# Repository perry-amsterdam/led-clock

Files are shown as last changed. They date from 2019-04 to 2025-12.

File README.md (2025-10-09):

# LED Clock with ESP32, FreeRTOS & WS2812B




A **DIY LED clock** built with WS2812B LEDs, an IKEA photo frame, laser-cut parts, and an **ESP32** running **FreeRTOS**.  
The hardware (clock face, laser-cut design) is ready ✅. The software runs on a modern ESP32 + FreeRTOS platform and is fully configurable through a captive Wi-Fi portal.

---

## ✨ Features

* Automatic time synchronization via **NTP**
* **Timezone detection** via IP geolocation
* **mDNS** discovery on the local network
* **WPS** connection option (Wi-Fi Protected Setup)

* Wi-Fi setup: if no connection is found, the clock starts an **Access Point + captive portal**
* Written in **C/C++ with FreeRTOS**
* Expandable platform: animations, integrations, and artistic variations
* Future **API server** + **Flutter app** for remote control

### FreeRTOS Tasks
- `task_wifi` – connect and reconnect to the network  
- `task_time` – synchronize and monitor time  
- `task_render` – draw the clock on the LED strip  
- `task_portal` – run the captive portal when offline  
- `task_led` – update the status LED  

---

## 🖥️ Software Setup

1. Install the required tools:
   * [Arduino CLI](https://arduino.github.io/arduino-cli/latest/) or [Arduino IDE](https://www.arduino.cc/en/software)  
   * ESP32 board support (via Board Manager)
   * `make` (for the workflow with the Makefile)
   * [Flutter](https://flutter.dev/) (optional, for the mobile app)

2. Use the **Makefile** for a quick workflow:

   ```bash
   make deps       # install esp32 core + libraries (Adafruit NeoPixel)
   make build      # compile
   make upload     # flash (PORT=/dev/ttyUSB0)
   make monitor    # serial monitor (115200 baud)
   ```

   Variables:
   - `PORT` – default `/dev/ttyACM0`
   - `BOARD` – default `esp32:esp32:esp32s3`
   - `FLASH_OPTS` – flash/PSRAM/partition settings

   Example:
   ```bash
   make PORT=/dev/ttyUSB0 MONITOR_BAUD=115200 monitor
   ```

3. First boot → configure Wi-Fi through the captive portal (`ESP32-Setup` / `configwifi`).

---

## ⚙️ Hardware Setup

* **Clock face** (laser-cut ✅, designed in LibreCAD):  
  Clock Face

* **WS2812B connectors**:
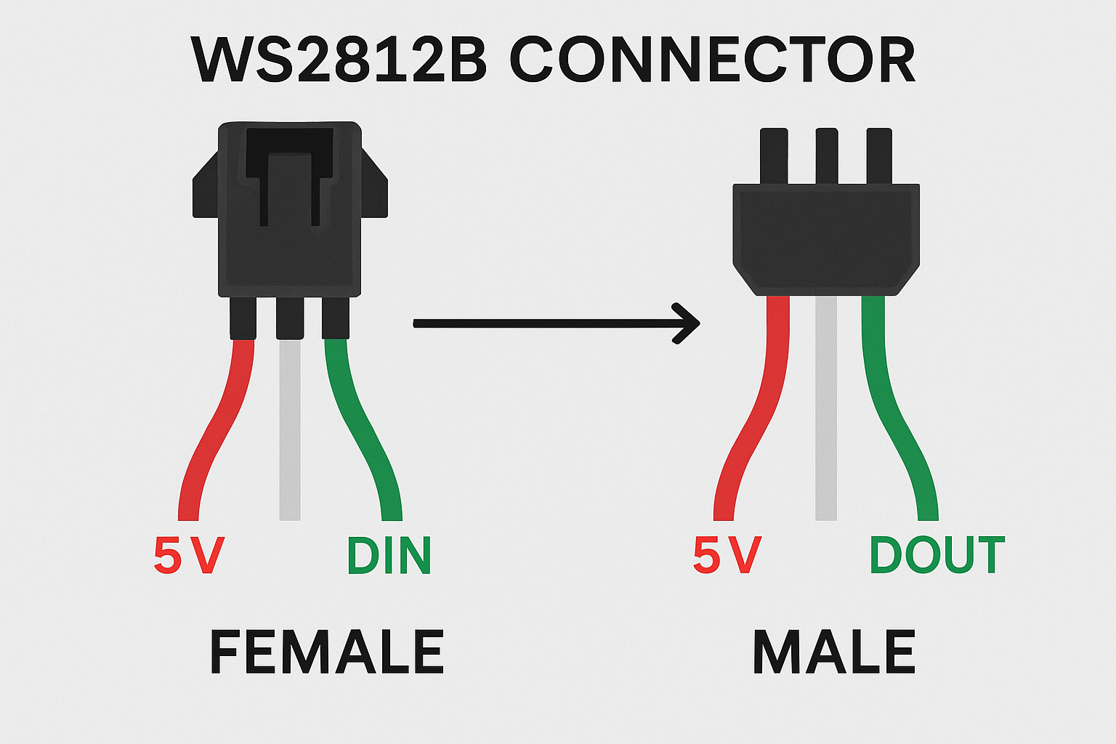
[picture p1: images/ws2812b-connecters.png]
Connector image
  

* **Parts list**:
  * IKEA frame 23x23 cm  
  * WS2812B LED strip or ring (5V)  
  * ESP32 devkit (WROOM/WROVER/S3)  
  * Cardboard/laser-cut front plate  

### Connections

- **GPIO 8** → DIN of the **clock LED strip (60 LEDs for minutes and seconds)**
- **GPIO 9** → DIN of the **clock LED strip (24 LEDs for 24 hours)**  
- **GPIO 48** → DIN of the **status LED**  
- **5V & GND** shared between ESP32 and all LEDs

### 📷 Wiring Diagram

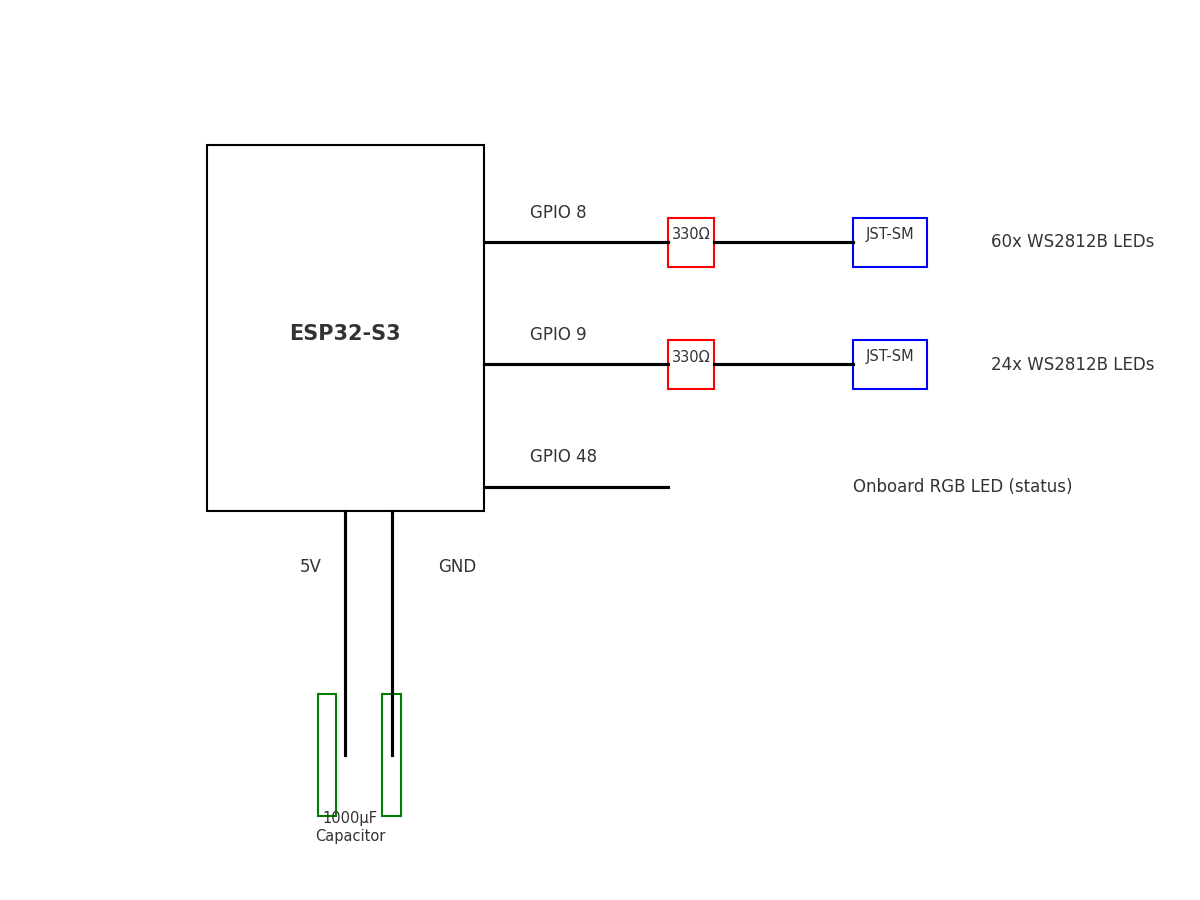
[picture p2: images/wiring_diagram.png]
Wiring Diagram


> ℹ️ The status LED (GPIO 48) is already present on the ESP32-S3 DevKit (built-in RGB LED).

### 📋 Pinout Table

| GPIO | Function | Description |
|---|---|---|
| 8 | Clock LEDs DIN  | Data input of WS2812B strip/matrix |
| 9 | Clock LEDs DIN  | Data input of WS2812B strip/matrix |
| 48 | Status LED (onboard) | Built-in RGB LED on ESP32 DevKit |
| 5V | LED Power | Ensure sufficient current capacity |
| GND  | Ground | Must be shared with LED power supply |

### 🔌 Power Consumption (approximate)

| LED Count | 100% brightness (mA) | 100% (A) | ~30% brightness (mA) | ~30% (A) |
|---:|---:|---:|---:|---:|
| 1 | 60 | 0.06 | 18 | 0.018 |
| 8 | 480 | 0.48 | 144 | 0.144 |
| 30 | 1800 | 1.80 | 540 | 0.54 |
| 60 | 3600 | 3.60 | 1080 | 1.08 |
| 100 | 6000 | 6.00 | 1800 | 1.80 |

**Tips**  
- Choose a power supply with **20–30% margin**  
- Use a **level shifter** for long LED strips  
- **GND** from the power supply must be connected to the ESP32  
- Lower `LED_BRIGHTNESS` to reduce power and heat

### NeoPixel Guidelines
1. **Capacitor** – 1000µF, 6.3V+ between V+ and GND  
2. **Resistor** – 300–500Ω in the data line  
3. **Level shifter** – recommended for 3.3V → 5V  

---

### 📡 Wi-Fi via WPS

Besides the captive portal, the clock also supports **WPS (Wi-Fi Protected Setup)** to connect to your network.  
This is useful if you don’t want to enter Wi-Fi credentials manually.

- **WPS PBC (Push Button Configuration)**: press the WPS button on your router and start the clock in WPS mode.  
- If the ESP32 successfully completes a WPS handshake, the credentials are stored in the chip’s NVS memory.  
- On the next boot, the clock automatically reconnects using these stored credentials.

⚠️ Note: not all ESP32 Arduino cores support WPS.  
Since **ESP32 Arduino core v3+**, `WiFi.beginWPSConfig()` has been removed. For those versions, use the captive portal instead.

---

## 🚀 Usage

1. Flash the firmware.  
2. On first boot, connect to **ESP32-Setup**.  
3. Open `http://192.168.4.1` and configure Wi-Fi.  
4. ESP32 connects → fetches time → displays clock on LED strips (GPIO 8 and 9).  
5. Status LED (GPIO 48) shows connection status.  

---

## 📸 Images

Frame
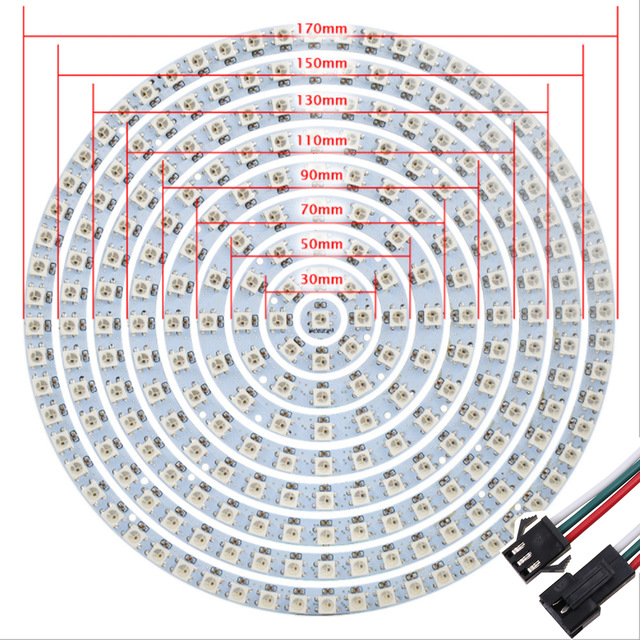
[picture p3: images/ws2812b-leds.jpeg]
WS2812B LEDs


---

## 🗺️ Roadmap

* [x] Laser-cut clock face  
* [x] Wi-Fi captive portal & NTP synchronization  
* [x] Automatic timezone detection via IP  
* [x] mDNS service  
* [ ] Wi-Fi WPS  
* [ ] API server on ESP32  
* [ ] Flutter app integration  
* [ ] Artistic clock variants  
* [ ] Animations & LED effects  
* [ ] Integration with Home Assistant / MQTT  
* [ ] Public release of PCB & 3D files  

---

## 🤝 Contributing

1. Fork the repo and create a feature branch:
   ```bash
   git checkout -b feature/new-feature
   ```
2. Commit your changes with clear messages  
3. Submit a Pull Request 🚀  

Tips: document hardware/software additions, add schematics or images, and keep commit messages short.

---

## 👤 Author

* **Perry Couprie** – initial development  
  GitHub: [perry-amsterdam](https://github.com/perry-amsterdam)

---

## 📐 CAD Tools

For designing parts such as the clock face and enclosure, you can use free open-source CAD tools:

### LibreCAD
* 2D CAD software, ideal for drawing the **laser-cut clock face**.
* Website: [https://librecad.org](https://librecad.org)

**Installation on Ubuntu:**
```bash
sudo apt update
sudo apt install librecad
```

### OpenSCAD
* 3D CAD software, perfect for designing **enclosures and 3D-printable parts**.
* Website: [https://openscad.org](https://openscad.org)

**Installation on Ubuntu:**
```bash
sudo apt update
sudo apt install openscad
```

Both programs are lightweight and available in the standard Ubuntu repositories.

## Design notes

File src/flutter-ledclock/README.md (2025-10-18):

# ledclock

A new Flutter project.

## Getting Started

This project is a starting point for a Flutter application.

A few resources to get you started if this is your first Flutter project:

- [Lab: Write your first Flutter app](https://docs.flutter.dev/get-started/codelab)
- [Cookbook: Useful Flutter samples](https://docs.flutter.dev/cookbook)

For help getting started with Flutter development, view the
[online documentation](https://docs.flutter.dev/), which offers tutorials,
samples, guidance on mobile development, and a full API reference.

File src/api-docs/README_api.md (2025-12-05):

# LED Clock REST API – Full Documentation

This directory contains the **OpenAPI specification** for the ESP32 LED Clock REST API.
The full specification is available in [`openapi.json`](./openapi.json) (version **1.5.0**).

---

## Overview

The LED Clock API provides system management and time-related endpoints for an ESP32-based LED clock running FreeRTOS. It enables you to:

* Check device health and uptime
* Reboot the system remotely
* Get or set the current timezone
* Retrieve a list of supported IANA timezones

All responses are in JSON format.

---

## Endpoints

### 🩺 `GET /api/ping`

**Purpose:** Check if the device is online and responding.

**Response Example:**

```json
{
  "pong": true,
  "now": 1733246400000,
  "uptime_ms": 52341,
  "heap_free": 187264,
  "wifi_mode": "AP"
}
```

**Fields:**

* `pong`: Always `true` if device is reachable.
* `now`: Current time in Unix epoch (ms).
* `uptime_ms`: Time since boot in milliseconds.
* `heap_free`: Free heap memory in bytes.
* `wifi_mode`: Current Wi-Fi mode (e.g., `AP`, `STA`).

---

### 🔁 `POST /api/system/reboot`

**Purpose:** Trigger a soft reboot of the ESP32 device.

**Response Example:**

```json
{
  "rebooting": true,
  "message": "Rebooting system..."
}
```

**Behavior:** The system will reboot within a few seconds after returning this response.

---

### 🌍 `GET /api/timezone`

**Purpose:** Retrieve the current timezone configuration.

**Response Example:**

```json
{
  "timezone": "Europe/Amsterdam",
  "gmtoffset": 3600,
  "dstoffset": 3600
}
```

**Fields:**

* `timezone`: Current IANA timezone string.
* `gmtoffset`: Base UTC offset in seconds (without DST).
* `dstoffset`: Daylight saving offset in seconds.

---

### 🕓 `POST /api/timezone`

**Purpose:** Update the timezone setting (IANA format only).

**Request Body:**

```json
{
  "timezone": "Europe/Amsterdam"
}
```

**Response Example:**

```json
{
  "success": true,
  "message": "Timezone cleared; using default",
  "timezone": "Etc/UTC",
  "gmtoffset": 0,
  "dstoffset": 0
}
```

**Notes:**

* This changes only the timezone configuration. The clock time continues to be managed by NTP/RTC.

---

### 🗑️ `DELETE /api/timezone`

**Doel:** Verwijder de ingestelde tijdzone (reset naar standaard/auto).

**Response Voorbeeld:**

```json
{
  "success": true,
  "message": "Timezone cleared; using default",
  "timezone": "Etc/UTC",
  "utc_offset_sec": 0
}
```

**Gedrag:** Idempotent. Als er geen user-tijdzone was ingesteld, blijft de response `success: true` en wordt de actieve (fallback) tijdzone gerapporteerd.

### 🌐 `GET /api/timezones`

**Purpose:** Retrieve a list of supported IANA timezones.

**Response Example:**

```json
{
  "timezones": [
    "Europe/Amsterdam",
    "America/New_York",
    "Asia/Tokyo"
  ]
}
```

### 🎨 `GET /api/themes`

**Purpose:** List all available themes.

**Response Example:**
```json
[
  {"id":"default","name":"Default","is_default":true,"is_active":true},
  {"id":"retro","name":"Retro","is_default":false,"is_active":false}
]
```

---

### 🎯 `GET /api/theme`

**Purpose:** Get the currently active theme and status.

**Response Example:**
```json
{
  "active_id": "retro",
  "active_name": "Retro",
  "is_default": false,
  "has_saved_override": true,
  "saved_override_id": "retro"
}
```

---

### ✅ `POST /api/theme?id=<ID>`

**Purpose:** Activate a theme by its `id` (also saved as user override).

**Success Response:**
```json
{
  "ok": true,
  "active_id": "retro",
  "active_name": "Retro",
  "is_default": false
}
```

**Errors:** `400` missing/invalid `id`, `404` unknown theme id.

---

### 🗑️ `DELETE /api/theme`

**Purpose:** Clear saved theme override and revert to default theme.

**Response Example:**
```json
{
  "ok": true,
  "active_id": "default",
  "active_name": "Default",
  "is_default": true
}
```

**Notes:**

* This is a compact list that can be expanded in future versions.

---

## Using the Specification

### 1. In Postman

1. Open **Postman**.
2. Go to **File → Import**.
3. Select `openapi.json`.
4. Postman automatically creates a collection with all endpoints.

### 2. In Swagger UI (locally or online)

You can visualize and test the API live in your browser:

1. Go to [https://editor.swagger.io/](https://editor.swagger.io/)
2. Open `openapi.json` via **File → Import File**.
3. The full API documentation will load, allowing you to test each endpoint interactively.

### 3. Generate Client Code

**Example (Go client via `oapi-codegen`):**

```bash
oapi-codegen -generate types,client -o ledclock_client.gen.go -package ledclock docs/openapi.json
```

**Supported generators:** Go (`oapi-codegen`), Python (`openapi-python-client`), TypeScript (`openapi-typescript`), etc.

### 4. Test with curl

If your ESP32 is reachable (e.g., in AP mode on `ledclock.local`):

```bash
curl http://ledclock.local/api/ping
curl -X POST http://ledclock.local/api/system/reboot
curl http://ledclock.local/api/timezone
curl -X POST -H "Content-Type: application/json" -d '{"timezone": "Europe/Amsterdam"}' http://ledclock.local/api/timezone
curl -X DELETE http://ledclock.local/api/timezone
curl http://ledclock.local/api/timezones
```

---

## Roadmap

* [ ] Add authentication (API key or JWT)
* [ ] Add `/api/time` for real-time NTP sync information
* [ ] Implement versioned API structure (`/v1`, `/v2`, ...)

---

**Maintainer:** Perry Couprie
**Project:** ESP32 LED Clock with FreeRTOS and WS2812B

---

*This API and documentation are licensed under the MIT License.*

---

## ⚡ `/api/powersave`

Beheert de energiebesparingsmodus van de LED-clock.

### **GET /api/powersave**

**Doel:** opvragen of powersave actief is.

**Response:**
```json
{ "enabled": true }
```

---

### **POST /api/powersave**

**Doel:** powersave in- of uitschakelen.

**Body:**
```json
{ "enabled": true }
```

**Response:**
```json
{ "enabled": true }
```

**Mogelijke fouten:**
- `400 Missing body`
- `400 Invalid JSON`
- `400 Missing field 'enabled'`
- `405 Method Not Allowed`

**Voorbeeld curl:**
```bash
curl -X POST http://ledclock.local/api/powersave \
  -H "Content-Type: application/json" \
  -d '{"enabled": true}'
```

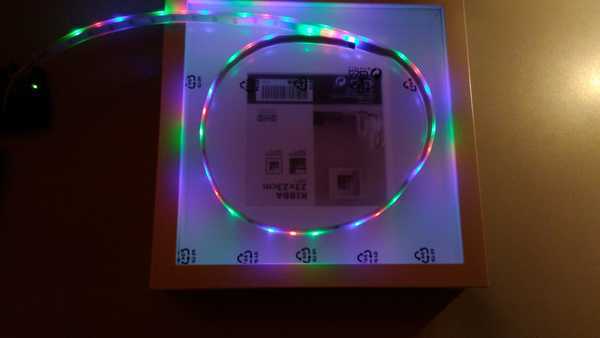
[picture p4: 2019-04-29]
images/picture-frame-with-leds.jpeg

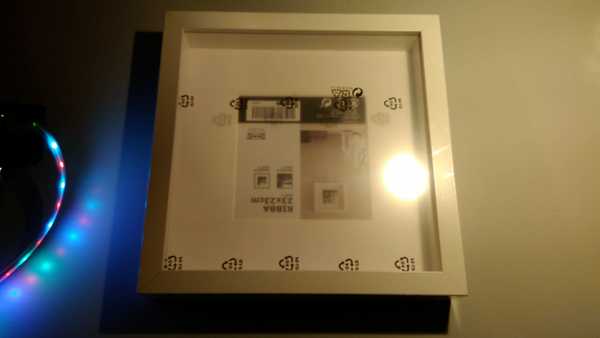
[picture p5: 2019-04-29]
images/picture-frame.jpeg

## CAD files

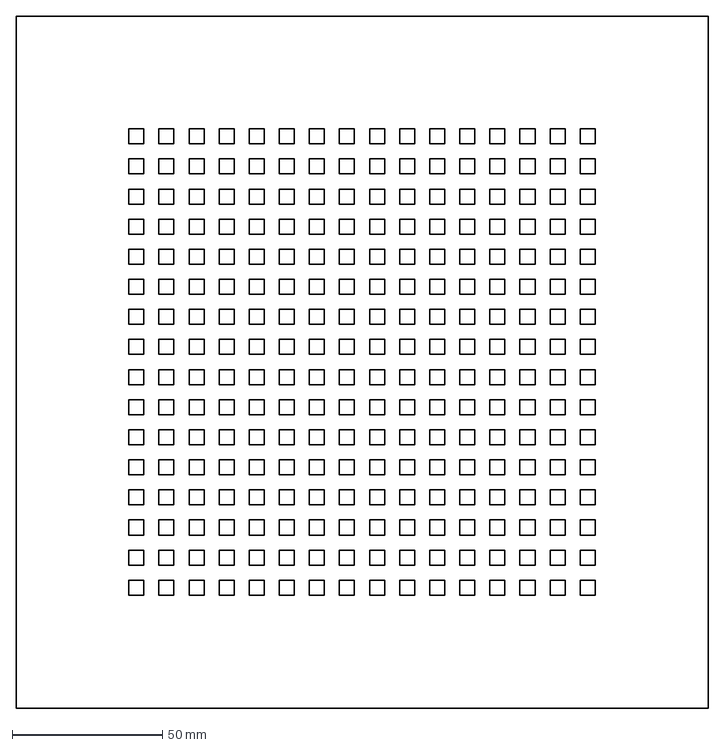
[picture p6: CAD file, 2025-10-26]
librecad/led-clock-matrix-face.dxf
230.0 x 230.0 mm

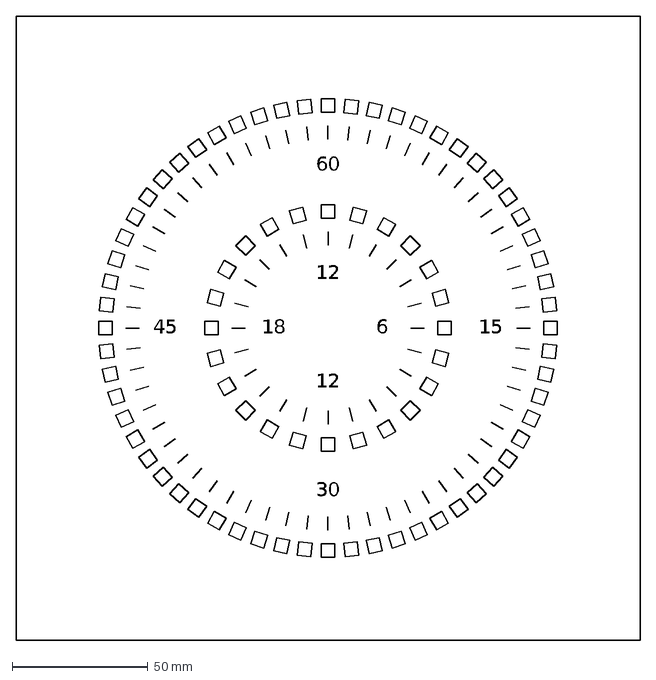
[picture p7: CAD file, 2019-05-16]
librecad/led-clock-face.dxf
60
15
45
12
6
18
30

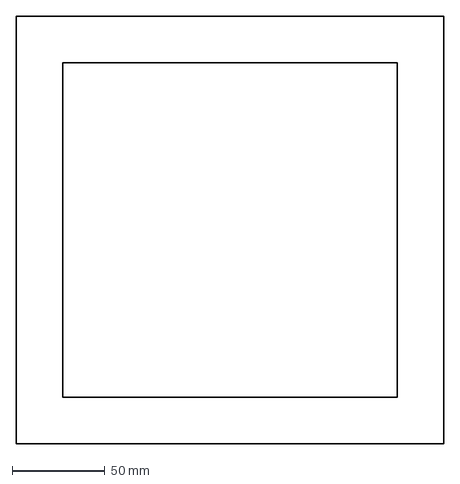
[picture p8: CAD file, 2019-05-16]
librecad/spacer.dxf
230.0 x 230.0 mm

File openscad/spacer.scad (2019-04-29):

difference()
{
cube([230,230,20]);
translate([5,5,0])cube([(230-10), (230 - 10), 20]);
}

translate([0,0,(25+20)])difference()
{
cube([230,230,7]);
translate([5,5,0])cube([(230-10), (230 - 10),7]);
}

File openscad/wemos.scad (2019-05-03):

// Function to create led clock electronics box.
module box(x,y,z,d) {

	// Box for clock electronics.
	difference()
	{
		cube([x, y ,z], center=true);
		translate([0,0,1*d])cube([x-(2*d), y-(2*d) ,z-2*d], center=true);
	}

	// Text on the side of the box.
	translate([0,-y/2,0])rotate([90,0,0])linear_extrude(height=3)text("Led clock electronics !!!", font="tohoma;styles=bold", halign="center", valign="center");

//
//	// Box lid.
//	difference()
//	{
//		union()
//		{
//			translate([0,50+25,0])cube([x, y ,d]);
//			translate([0+d,50+25+d,d])cube([(x - 2*d), (y-(2*d)) ,d]);
//		}
//
//		for(repeat = [0, 50,100,150])
//		{
//			for(count = [0,5,10,15,20])
//			{
//				translate([repeat + 10,60+25+count + d,0])cube([30, 2*d/4 ,2*d]);
//			}
//		}
//		
//		translate([d+d,50+25+d+d,d])cube([(x - 4*d), (y-(4*d)) ,d]);
//	}
//
	// Box dividers.
	for(count = [50,100,150])
	{
//		difference()
//		{	
			translate([-x/2 + d + count,0,0])cube([d,y,z], center=true);
//			translate([count,d,(z-2*d-d*1)])cube([d,2*d,2*d]);
//		}
	}
}

// Call to function, to create the box.
box(200,50,30,3);

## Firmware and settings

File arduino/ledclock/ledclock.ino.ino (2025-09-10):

// ==== ESP32: Minimal Wi-Fi Test met Captive Portal (zonder FreeRTOS) ====
// - Probeert verbinden met opgeslagen Wi-Fi
// - Faalt? Start Access Point + webportal om SSID/WPA in te voeren
// - Na opslaan -> reboot en verbindt

#include <WiFi.h>
#include <WebServer.h>
#include <DNSServer.h>
#include <Preferences.h>

Preferences prefs;
WebServer server(80);
DNSServer dns;

const char* PREF_NS  = "wifi";
String savedSsid, savedPass;

const char* AP_SSID  = "ESP32-Setup";
const char* AP_PASS  = "configwifi"; // min. 8 chars
const byte  DNS_PORT = 53;
IPAddress   AP_IP(192,168,4,1), AP_GW(192,168,4,1), AP_MASK(255,255,255,0);

// -------- helpers --------
String htmlWrap(const String& body) {
  return String(F(
    "<!doctype html><html><head><meta charset='utf-8'/>"
    "<meta name='viewport' content='width=device-width,initial-scale=1'/>"
    "<title>ESP32 Wi-Fi setup</title>"
    "<style>body{font-family:system-ui,-apple-system,Segoe UI,Roboto,Arial;"
    "max-width:520px;margin:2rem auto;padding:0 1rem}"
    "form{display:grid;gap:.75rem}input,button{font-size:1rem;padding:.6rem}"
    "button{cursor:pointer}</style></head><body>"
  )) + body + F("</body></html>");
}

void handleRoot() {
  String body = F(
    "<h1>ESP32 Wi-Fi configuratie</h1>"
    "<form method='POST' action='/save'>"
    "<label>SSID<br><input name='ssid' required placeholder='Bijv. MijnWiFi'></label>"
    "<label>Wachtwoord<br><input name='pass' type='password' required></label>"
    "<button type='submit'>Opslaan</button>"
    "</form>"
    "<p><a href='/reset'>Opgeslagen gegevens wissen</a></p>"
  );
  server.send(200, "text/html", htmlWrap(body));
}

void handleSave() {
  if (!server.hasArg("ssid") || !server.hasArg("pass")) {
    server.send(400, "text/plain", "Ontbrekende velden");
    return;
  }
  String ssid = server.arg("ssid");
  String pass = server.arg("pass");

  prefs.begin(PREF_NS, false);
  prefs.putString("ssid", ssid);
  prefs.putString("pass", pass);
  prefs.end();

  server.send(200, "text/html", htmlWrap(
    "<h1>Opgeslagen ✅</h1><p>Herstart en verbinden met <b>" + ssid + "</b>...</p>"
  ));
  delay(600);
  ESP.restart();
}

void handleReset() {
  prefs.begin(PREF_NS, false);
  prefs.clear();
  prefs.end();
  server.send(200, "text/html", htmlWrap("<h1>Gewist ✅</h1><p>Herstart...</p>"));
  delay(600);
  ESP.restart();
}

static bool isIpLike(const String& h) {
  int dots=0;
  for (size_t i=0;i<h.length();i++){
    if (h[i]=='.'){ dots++; continue; }
    if (!isDigit(h[i])) return false;
  }
  return dots==3;
}

void handleNotFound() {
  // Captive portal: alles omleiden naar / als host niet ons AP-IP is
  if (!isIpLike(server.hostHeader()) && server.hostHeader() != AP_IP.toString()) {
    String loc = "http://" + AP_IP.toString();
    server.sendHeader("Location", loc, true);
    server.send(302, "text/plain", "");
    return;
  }
  handleRoot();
}

// -------- Wi-Fi --------
bool connectWiFi(const String& ssid, const String& pass, uint32_t timeoutMs=15000) {
  if (ssid.isEmpty()) return false;

  Serial.printf("Verbinden met SSID='%s'...\n", ssid.c_str());
  WiFi.mode(WIFI_STA);
  WiFi.disconnect(true, true);
  delay(50);
  WiFi.begin(ssid.c_str(), pass.c_str());

  uint32_t start = millis();
  while (WiFi.status() != WL_CONNECTED && (millis() - start) < timeoutMs) {
    delay(250);
    Serial.print('.');
  }
  Serial.println();

  if (WiFi.status() == WL_CONNECTED) {
    Serial.print("Verbonden! IP: ");
    Serial.println(WiFi.localIP());
    return true;
  }
  Serial.println("Verbinden mislukt.");
  return false;
}

void startPortal() {
  Serial.println("Start AP + portal...");
  WiFi.mode(WIFI_AP);
  WiFi.softAPConfig(AP_IP, AP_GW, AP_MASK);
  if (!WiFi.softAP(AP_SSID, AP_PASS)) {
    Serial.println("AP starten mislukt!");
    return;
  }
  dns.start(DNS_PORT, "*", AP_IP);

  server.on("/", HTTP_GET, handleRoot);
  server.on("/save", HTTP_POST, handleSave);
  server.on("/reset", HTTP_GET, handleReset);
  server.onNotFound(handleNotFound);
  server.begin();

  Serial.printf("AP actief: %s  (http://%s)\n", AP_SSID, AP_IP.toString().c_str());
}

void stopPortal() {
  server.stop();
  dns.stop();
  WiFi.softAPdisconnect(true);
  Serial.println("Portal gestopt.");
}

// -------- Arduino lifecycle --------
void setup() {
  Serial.begin(115200);
  delay(300);
  Serial.println("\nBoot Wi-Fi test...");

  // opgeslagen credentials
  prefs.begin(PREF_NS, true);
  savedSsid = prefs.getString("ssid", "");
  savedPass = prefs.getString("pass", "");
  prefs.end();

  // 1) Probeer Wi-Fi
  if (connectWiFi(savedSsid, savedPass)) {
    Serial.println("Klaar: STA verbonden.");
  } else {
    // 2) Start AP + portal
    startPortal();
  }
}

void loop() {
  // Draai portal alleen als AP actief is
  if (WiFi.getMode() == WIFI_AP || WiFi.getMode() == WIFI_AP_STA) {
    dns.processNextRequest();
    server.handleClient();
  }

  // Optioneel: als we intussen verbinding kregen, kun je portal uitzetten:
  if (WiFi.status() == WL_CONNECTED && WiFi.getMode() != WIFI_STA) {
    stopPortal();
    WiFi.mode(WIFI_STA);
    Serial.print("Verbonden! IP: ");
    Serial.println(WiFi.localIP());
  }
}

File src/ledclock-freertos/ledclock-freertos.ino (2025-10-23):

#include <Arduino.h>
#include "rtos.h"
#include "hal_time_freertos.h"
#include "globals.h"
#include "status_led.h"
#include "task_led.h"
#include "task_wifi.h"
#include "task_time.h"
#include "task_render.h"
#include "task_mdns.h"
#include <config_storage.h>
#include <theme.h>
#include <theme_manager.h>

#if !defined(ESP_ARDUINO_VERSION_MAJOR) || (ESP_ARDUINO_VERSION_MAJOR < 3)
#error "This project requires Arduino-ESP32 core v3.0.0 or higher"
#endif

void setup()
{

	// init dedicated mDNS task
	mdnsTaskInit();

	// Clear the minuts/seconds and hour leds.
	if (theme_is_set())
	{
		String savedId;
		if (loadThemeId(savedId))
		{
			themeInit(savedId.c_str());
		} else
		{
			themeInit("");
		}
	}
	else
	{
		themeInit("");
	}

	// Clear the status led.
	ledOff();

	// Wacht 5 seconden.
	if (DEBUG_START_DELAY)
	{
		hal_delay_ms(5000);
	}

	Serial.begin(115200);
	hal_delay_ms(50);
	Serial.println("\r[Boot] Start (FreeRTOS)");

	// korte test van de status-LED
	ledBegin();
	ledSelfTest();

	// Create RTOS primitives
	g_sysEvents = xEventGroupCreate();

	// Create tasks
	xTaskCreatePinnedToCore(task_led,    "led",    STACK_LED,    nullptr, PRIO_LED,    nullptr, 1);
	xTaskCreatePinnedToCore(task_wifi,   "wifi",   STACK_WIFI,   nullptr, PRIO_WIFI,   nullptr, 1);
	xTaskCreatePinnedToCore(task_time,   "time",   STACK_TIME,   nullptr, PRIO_TIME,   nullptr, 1);
	xTaskCreatePinnedToCore(task_render, "render", STACK_RENDER, nullptr, PRIO_RENDER, nullptr, 0);

	// --- Stack debug boot summary ---
	hal_delay_ms(500);			 // even wachten zodat alle tasks gestart zijn
	if (STACK_DEBUG)
	{
		Serial.println("[stack] first samples:");
	}
	LOG_STACK_WATERMARK("time");
	LOG_STACK_WATERMARK("wifi");
	LOG_STACK_WATERMARK("render");
	LOG_STACK_WATERMARK("led");
}


void loop()
{
	// Nothing to do here; tasks run under FreeRTOS.
	vTaskDelay(pdMS_TO_TICKS(1000));
}

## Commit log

2019-04-29 Create directory for openscad amd librecad
    [led-clock-face.dxf, spacer.scad, wemos.scad]
2019-05-08 Updated drawing
    [led-clock-face.dxf]
2019-05-16 Updated drawings for laser cutting and updated code.
    [led-clock-face.dxf, spacer.dxf]
2024-12-07 Refactor fetch_time.cpp: Encapsulate functionality in TimeInfo class with debug support
    - Introduced `TimeInfo` class to encapsulate logic for public IP, timezone, DST, and NTP time retrieval.
    - Moved the previous procedural code into methods of the `TimeInfo` class to improve code organization and readability.
    - Added a `debugLog` method to control debug output, making it optional based on the `debug` flag.
    - Refactored `getPublicIP`, `getTimezoneAndDST`, `getCurrentTimeFromNTP`, and `extractTimeDetails` methods to use the `TimeInfo` class.
    - Enhanced debug logging for better traceability during execution.
    - Updated main function to instantiate `TimeInfo` with a debug flag and call its meth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
2024-12-14 Refactor NeoPixel Clock Code for Modularity and Efficiency
    - Replaced `rainbow` function with `displayRainbow`, simplifying and focusing on the rainbow effect.
    - Lowered rainbow brightness by adjusting `ColorHSV` brightness value to 100 for better visual balance.
    - Moved time retrieval logic to `retrieveTime` function for modularity.
    - Added `updateClockDisplay` function to overlay clock LEDs on top of the rainbow effect.
    - Decoupled clock logic from the rainbow animation, allowing independent execution in the loop.
    - Cleaned up redundant comments and improved readability of the setup and loop functions.
    - Updated loop structure to call `displayRainbow` first as a background effect, followed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
2025-08-20 feat: add setup script for Zephyr + ESP32 development on Ubuntu
    Includes:
    - Full and minimal installation modes
    - Clean mode to remove environment
    - Helper functions and added to ~/.bashrc
    - Fix for python3-future installation via pip
    - Automated test build (hello_world on native_sim)
2025-09-04 Updated Makefile en script for ESP32‑S3‑WROOM‑1‑N16R8‑module (16 MB flash en 8 MB PSRAM)
2025-09-10 The rgb led now displays wifi status.
2025-09-16 Refactor: vervang Arduino millis/delay door hal_time API
    globals.h: macros toegevoegd om direct gebruik van millis/delay te blokkeren
    ledclock.ino: gebruik hal_millis() en hal_delay_ms() i.p.v. Arduino functies
    net_time.cpp, portal.cpp, wifi.cpp: alle delay/millis-calls vervangen door hal_time wrappers
    includes uitgebreid met hal_time.h
    kleine code-style verbeteringen in wifi.cpp (if-block formatting)
    [diff.txt]
2025-09-17 Updated ws2812b code en added ws2812b code to de main program
2025-09-17 Added mdns to make the clock availiable local via hostname ledclock.local
2025-09-21 Added ledclock-freertos
2025-09-22 Added missing function netTimeMaintain
    [net_time.cpp]
2025-09-24 only compile code voor arduino vore v3+
2025-09-28 Status led is less bright now.
2025-09-29 KiCad stuff
    [ledclock.kicad_pcb, ledclock.kicad_sch]
2025-09-30 fixed status led
2025-10-03 Added een api
2025-10-05 fixed wifi up en down status.
    [task_wifi.cpp]
2025-10-05 Fixed wifi up status
    [task_wifi.cpp]
2025-10-08 Renamed arduino to src
2025-10-10 Fixed mdns i hope :-)
    [http_api.cpp, http_portal.cpp, ledclock-freertos.ino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]
2025-10-10 Display better time en uptime in de GoClient
2025-10-18 Add Flutter frontend (flutter-ledclock)
2025-12-05 Added powersave mode
2025-12-05 Added powersafe to the api
2025-12-05 Added powerave option to the app
2025-12-06 Added powersave delete funtion to the api specs
2025-12-06 Added powersave delete to de api server.
2025-12-07 fixed powersave mode, it works now
    [task_render.cpp, task_time.cpp]
2025-12-14 Added code for led display
2026-06-07 Fix Arduino library dependencies
